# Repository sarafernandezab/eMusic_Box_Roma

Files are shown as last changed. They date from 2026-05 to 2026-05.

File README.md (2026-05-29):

# eMusic Box Roma (eMB Roma)

This repository contains the open-source hardware files, firmware, Max/MSP control patches, musical stimuli, configuration files, and supplementary Python scripts associated with the methodological paper:

> *The e-Music Box Roma: An open research tool for accessible joint music making*  
> Sara F. Abalde, Félix Bigand, Lorenzo Orciari, Claudio Lorini, Peter E. Keller, Alberto Parmiggiani, Marco Crepaldi, Giacomo Novembre    

The eMusic Box Roma (eMB Roma) is an open instrument for accessible music making. It combines a 3D-printed rotary interface, embedded electronics, custom firmware, and Max/MSP software for interactive musical stimulus presentation and experimental control. The system supports both solo and dual use.

---

## Repository structure

```text
.
├── hardware/
│   └── 3D_printing_STL_files
│
├── firmware/
│
├── software/
│   ├── solo_eMB_MaxMSP/
│   └── dual_eMB_MaxMSP/
│
├── musical_stimuli/
│   ├── example_MIDI/
│   └── example_MIDI_derived_text_eMB/
│
├── configs/
│   ├── global/
│   └── experiments/
│
├── supplementary/
│   ├── config_generation/
│   └── analysis/
│
└── README.md
```

---

## Hardware design and construction

The `hardware/3D_printing_STL_files/` folder contains the STL files required to fabricate the eMB Roma enclosure.

The mechanical design is organized according to the three main structural groups described in the paper: base, cover, disk support, rotary disk and locking rings (both inner and outer).

The STL files correspond to the printable components of the eMB Roma illustrated in Figure 2. In the implementation described in the paper, parts were printed in Nylon PA 6-6, although other materials may be used depending on experimental or fabrication constraints.

Additional non-printed mechanical components include the rotating handle, ball bearing, ferrite ring, and self-tapping screws. Assembly details, screw sizes, and component placement are documented in the main paper.

---

## Electronic architecture

The eMB Roma integrates:

- a magnetic rotary encoder for measuring disk rotation,
- a linear slider,
- a push button,
- and a microcontroller for data acquisition and USB communication.

The firmware and software assume that all input signals are streamed from the microcontroller to the core computer through a serial connection over USB.

Hardware-specific wiring diagrams, component lists, and assembly notes are documented in the paper.

---

## Firmware and data communication

The firmware is located in:

```text
firmware/emb_firmware.ino
```

The firmware needs to be uploaded to the microcontroller during initial device setup. During routine use, it reads:

- rotary angle from the magnetic rotary encoder,
- slider position from the linear potentiometer,
- push button state from the digital input.

These values are streamed to the core computer through a serial COM port using ASCII-encoded messages.

The firmware includes device-specific calibration parameters. In particular, the angular zero position can be adjusted using the `value_offset_zero` parameter. This corrects for small differences in encoder and magnet alignment after assembly.

The direction of rotation can also be configured in the firmware. By default, the eMB Roma is set to clockwise rotation. This can be inverted by changing the `rotation_direction` parameter from `CW` to `CCW`. After changing the rotation direction, the zero-reference parameter may need to be verified or adjusted.

Once the firmware has been uploaded and calibration is complete, the Arduino environment should be closed so that the serial port is available to the Max/MSP control patch.

---

## Software architecture and experimental control

Two ready-to-use Max/MSP projects are provided, located in:

| Folder | Description |
|---|---|
| `software/solo_eMB_MaxMSP/` | Max/MSP patch for solo eMB use. |
| `software/dual_eMB_MaxMSP/` | Max/MSP patch for dual eMB use. |

The Max/MSP patch provides a graphical interface for:

- loading configuration files,
- selecting musical stimuli,
- assigning instruments to eMB devices,
- receiving serial data from the eMB,
- mapping rotational position to musical events,
- playing MIDI output streams,
- logging behavioral and musical data,
- and sending optional synchronization triggers to external systems.

---

## Configuration files

Configuration files are located in:

```text
configs/
```

The software uses two main types of configuration files:

| Folder | Description |
|---|---|
| `configs/global/` | Global configuration files containing setup-wide parameters such as COM ports, sampling rate, stimulus paths, output paths, instrument assignments, metronome settings, and optional trigger settings. |
| `configs/experiments/` | Trial-specific experiment configuration files, with one row per trial. These files define parameters such as trial number, condition, song, number of bars, instrument assignment, metronome tempo, and number of metronome beats. |

Configuration files are plain-text files and can be generated automatically using the supplementary Python scripts.

---

## Musical stimuli

Musical stimuli are located in:

```text
musical_stimuli/
```

The eMB Roma uses MIDI-derived text files that can be read by the Max/MSP patch and synchronized with the rotational position of the device. The MIDI derived text are created from the original MIDI using the Python code provided in pipeline_convert_MIDI_to_eMBtxt.py.

| Folder | Description |
|---|---|
| `musical_stimuli/example_MIDI/` | Original MIDI files separated by instrument. |
| `musical_stimuli/example_MIDI_derived_text_eMB/` | Text-based MIDI-derived stimulus files used by the Max/MSP patch. |

By default, one full rotation of the eMB corresponds to one musical bar divided into 16 equally spaced steps, matching the sixteenth-note structure of a 4/4 bar. Each row of a MIDI-derived text file represents a discrete temporal frame. Notes are encoded using MIDI-style values such as pitch, velocity, and duration.

Polyphonic stimuli are supported by including multiple note triplets in the same temporal frame. Frames without musical events are represented as silence.

The conversion scripts support batch conversion of MIDI files and can extract metadata such as tempo and bar count. If a MIDI file contains multiple instruments, the instrumental parts should be separated before conversion, with filenames indicating the corresponding instrument.

---

## Supplementary Python scripts

Supplementary scripts are located in:

```text
supplementary/
```

These scripts support reproducible preparation of files used by the eMB Roma system.

| Folder | Description |
|---|---|
| `supplementary/config_generation/` | Python scripts for generating global and experiment configuration files. |
| `supplementary/utilities/` | Additional utility scripts for preparing or checking repository resources. |
| `supplementary/analysis/` | Optional scripts for inspecting or analyzing output files. |

Example:

```bash
python supplementary/config_generation/create_configs.py
```

---

## Trial execution and data output

During a trial, the Max/MSP patch receives the continuous angular position of each eMB and discretizes it into temporal bins. The discretized within-bar position is combined with the completed rotation count to determine the absolute position in the musical sequence. This absolute position is then used to trigger the corresponding MIDI-derived musical event.

For each completed trial, the Max/MSP patch can save:

1. a raw text data file containing timestamped eMB data,
2. a MIDI file containing the musical output streams,
3. and, when enabled, a summary log file.

The raw text data file contains the main behavioral data used for analysis, including angular position, discretized musical position, rotation cycle count, and instrument information for each connected eMB.

---

## Example use cases

The eMB Roma supports different experimental and musical configurations along two main dimensions:

1. **Musical complexity**  
   The system can be configured for monophonic or polyphonic playback, single or multiple instruments, identical or complementary musical streams, and optional real-time parameter modulation through the linear slider.

2. **Social configuration**  
   The system supports solo use with one eMB and dual use with two eMBs. The repository provides separate Max/MSP patches for these two validated configurations.

Example dual-use configurations include:

- **Unison duet**: both eMBs play the same instrument and musical sequence.
- **Counterpoint duet**: the eMBs play different but complementary musical lines.
- **Band-like duet**: one eMB controls melodic streams while the other controls rhythmic or harmonic streams.

Multi-user setups beyond two devices may be possible with additional software and synchronization development, but they are not included as ready-to-use configurations in this repository.

---

## Quick start

Clone the repository:

```bash
git clone https://github.com/sarafernandezab/eMusic_Box_Roma.git
cd eMusic_Box_Roma
```

Upload the firmware to the microcontroller using the Arduino environment.

Then open the appropriate Max/MSP project:

```text
software/solo_eMB_MaxMSP/
```

or:

```text
software/dual_eMB_MaxMSP/
```

Load the global and experiment configuration files from `configs/`, then select the desired musical stimuli from `musical_stimuli/example_MIDI_derived_text_eMB/` or create your own musical stimuli with the same format.

---

## Dependencies

The repository may require:

- Arduino IDE or compatible Arduino development environment,
- AS5047P Arduino library,
- Max 8 or later,
- Python 3
  
---

## Citation

If you use this repository, please cite:

```bibtex
@article{emb_roma,
  title={The e-Music Box Roma: An open reasearch tool for accessible joint music making},
  author={Abalde, Sara F. and Bigand, Félix and Orciari, Lorenzo and others},
  journal={...},
  year={2026}
}
```

## Contact

For questions, bug reports, or suggestions regarding the eMB Roma system, please contact:

**Sara Fernández Abalde**  
sara.abalde@iit.it

Please include "eMB Roma" in the subject line when reporting issues.

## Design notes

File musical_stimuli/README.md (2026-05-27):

# Musical stimuli

This folder contains the musical materials used by the eMusic Box Roma (eMB Roma), including example MIDI files, MIDI-derived text files formatted for playback by the eMB, and the Python conversion pipeline used to generate them.

The musical stimuli are designed to be synchronized with the rotational data from the eMBs. During playback, the Max/MSP patch reads the MIDI-derived text files frame by frame and maps each frame to the current rotational position of the eMB handle.

---

## Folder structure

```text
musical_stimuli/
├── README.md
├── pipeline_convert_MIDI_to_eMBtxt.py
├── examples_MIDI/
└── example_MIDI_derived_text_eMB/
```

| File or folder | Description |
|---|---|
| `pipeline_convert_MIDI_to_eMBtxt.py` | Python pipeline for converting standard MIDI files into eMB-compatible text files. |
| `examples_MIDI/` | Example MIDI files, separated by instrument, including versions of *Thriller*, *Freed from Desire*, *Get Down on It*, and *We Found Love*. |
| `example_MIDI_derived_text_eMB/` | MIDI-derived text files generated from the example MIDI files and ready to be loaded by the eMB Max/MSP patch. |

---

## Musical stimulus format

All musical materials must be formatted so they can be interpreted and synchronized with the rotational data from the eMB. The eMB system uses simplified text-based representations converted from standard MIDI files.

By default, one full rotation of the eMB corresponds to one musical bar divided into 16 equally spaced steps. This matches the sixteenth-note structure of a 4/4 bar. Each step represents a fixed temporal frame in which one or more musical events may occur.

Each note is represented using MIDI-style values:

```text
pitch velocity duration
```

where:

- `pitch` is the MIDI pitch value,
- `velocity` determines the loudness or intensity of the note,
- `duration` specifies the temporal length of the note.

Polyphonic events are represented by including multiple pitch-velocity-duration triplets in the same row. Frames without musical events are represented as silence, with MIDI values set to zero.

---

## Example stimuli

The folder `examples_MIDI/` contains example MIDI files for different instrumental parts. The examples include versions of:

- *Thriller*
- *Freed from Desire*
- *Get Down on It*
- *We Found Love*

The MIDI files are organized as separate instrument streams, such as drums, bass, keyboards, and violin or melody. Each instrumental part should be saved separately before conversion.

The corresponding eMB-ready text files are provided in:

```text
example_MIDI_derived_text_eMB/
```

These files can be loaded directly by the Max/MSP patch according to the paths specified in the global configuration file.

---

## Converting MIDI files to eMB text files

The conversion from MIDI to eMB-compatible text files is performed with:

```text
pipeline_convert_MIDI_to_eMBtxt.py
```

This script converts standard MIDI files into simplified text files that can be read by the Max/MSP patch during eMB playback.

The conversion pipeline supports:

- conversion of MIDI files separated by instrument,
- polyphonic MIDI sequences,
- batch conversion of multiple MIDI files,
- extraction of stimulus metadata such as tempo and number of frames,
- generation of text files compatible with the eMB rotational mapping.

If a MIDI file contains multiple instruments, the instrumental parts should be separated into different files before conversion. Filenames should indicate the corresponding song and instrument, for example:

```text
Freed_bass.mid
Freed_drums.mid
Freed_keyboard.mid
Freed_violin.mid
```

The generated text files should follow the same naming logic:

```text
Freed_bass.txt
Freed_drums.txt
Freed_keyboard.txt
Freed_violin.txt
```

---

## Using the stimuli in Max/MSP

At the start of an eMB session, the Max/MSP patch loads the MIDI-derived text files according to the paths defined in the global configuration file.

During playback:

1. the eMB streams rotational data to the computer,
2. the Max/MSP patch discretizes the angular position into temporal frames,
3. the corresponding row of the MIDI-derived text file is read,
4. the musical event for that frame is played through the assigned MIDI instrument stream.

This structure allows individual instrument streams to be flexibly assigned, combined, or synchronized across one or two eMB devices.

---

## Notes on editing stimuli

The MIDI-derived text format can be edited manually in any text editor or regenerated by modifying the Python conversion pipeline.

For example, to transpose a stimulus down by one octave, subtract `12` from the pitch value of each note.

When editing files manually, preserve the row structure so that the number and order of frames remain compatible with the Max/MSP patch and the expected rotational mapping.

---

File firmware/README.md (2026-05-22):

# eMB Roma Firmware

This folder contains the Arduino firmware (eMB_firmware.ino) used to operate the eMusic Box Roma after assembly.

The firmware acquires:

- rotary angle data from the AS5047P magnetic rotary encoder,
- linear slider position,
- push button state,

and streams these values in real time to the core computer through a serial USB connection.

---

## Hardware requirements

The firmware was developed for:

- Adafruit Feather M0 microcontroller
- AS5047P magnetic rotary encoder
- Linear slider potentiometer
- Push button

The AS5047P encoder communicates with the microcontroller through SPI.

---

## Dependencies

Install the following Arduino library before compiling:

- AS5047P Arduino library  
  https://github.com/jonas-merkle/AS5047P

---

## Firmware configuration

Two parameters may need to be adjusted for each individual eMB after assembly:

```cpp
float value_offset_zero = 118.0;
RotationDirection rotation_direction = CW;
```

### Zero-position calibration

`value_offset_zero` defines the angular offset corresponding to the desired 0° position of the device.

After assembling the eMB:

1. Upload the firmware.
2. Open the Arduino serial monitor.
3. Rotate the device to the desired zero position.
4. Adjust `value_offset_zero` until the reported angle corresponds to 0°.

This calibration only needs to be performed once unless the encoder or magnet position changes.

---

## Rotation direction

The direction of rotation can be configured as:

```cpp
CW
```

or:

```cpp
CCW
```

Clockwise (`CW`) rotation is the default behavior.

---

## Serial output

The firmware streams ASCII-encoded values through the serial port at 9600 baud in the following format:

```text
slider_value corrected_angle
```

Example:

```text
523 142.31
```

---

## Uploading the firmware

1. Open the `.ino` file in the Arduino IDE.
2. Select the correct board and COM port.
3. Compile and upload the firmware.
4. Close the Arduino serial monitor before starting the Max/MSP patch so the serial port becomes available.

---

## Related software

The streamed serial data are used by the Max/MSP control patches located in:

```text
software/max_msp/
```

These patches handle:

- real-time acquisition,
- musical event mapping,
- MIDI playback,
- synchronization,
- and experimental control.

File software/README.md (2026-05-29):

# eMB Roma — Max/MSP Projects

Max/MSP projects for real-time musical interaction and experimental control using the eMB Roma devices.

This repository contains two versions of the Max/MSP implementation:

```text
solo_eMB_maxMSP/
dual_eMB_maxMSP/
```

Both projects share the same software architecture and functionality as described in the article. The main difference is the number of supported eMB devices:

* `solo_eMB_maxMSP` → setup for one eMB
* `dual_eMB_maxMSP` → setup for two simultaneous eMBs

---

## Project Structure

```text
solo_eMB_maxMSP/
│
├── eMB_solo_.maxpat
├── data/
├── other/
└── patchers/

dual_eMB_maxMSP/
│
├── eMB_dual_.maxpat
├── data/
├── other/
└── patchers/
```

---

## Features

* Real-time eMB rotational data acquisition
* Musical stimulus playback
* MIDI generation from movement
* Experimental trial control
* Instrument mapping
* Behavioral data logging
* Optional synchronization triggers for external devices

Both versions support:

* configurable experimental trials
* polyphonic musical stimuli
* MIDI-derived text sequences
* external MIDI routing

---

## Running the Projects

1. Open the desired project:

   * `solo_eMB_maxMSP/main.maxpat`
   * `dual_eMB_maxMSP/main.maxpat`

2. Load:

   * global configuration file
   * experiment configuration file

3. Connect the eMB device(s)

4. Start DSP/audio, and activate the patch data flow by pressing X.

5. After selecting the desired experiment, trial and song, press `Start Trial` in O

---

## Configuration Files

Each project uses two configuration files:

### Global Configuration

Defines:

* COM ports
* sampling rate
* paths
* instrument assignments
* trigger settings

### Experiment Configuration

Defines trial-specific parameters:

* song
* condition
* instrument mapping
* tempo
* metronome settings

---

## Musical Stimuli

Stimuli are stored as MIDI-derived text files:

```text
<song>_<instrument>.txt
```

Supported:

* monophonic and polyphonic MIDI-derived sequences
* multiple instruments
* configurable mappings

---

## Outputs

Each trial generates:

* raw behavioral data logs
* MIDI output files
* optional summary logs

---

## Screenshots

### GUI Overview

* Graphical user interface view with MaxMSP locked, for easier visualization and interaction with the eMB Roma. Press X to start the eMB connection and O to start a trial after loading the experimental configuration file and corresponding  trial (and song).

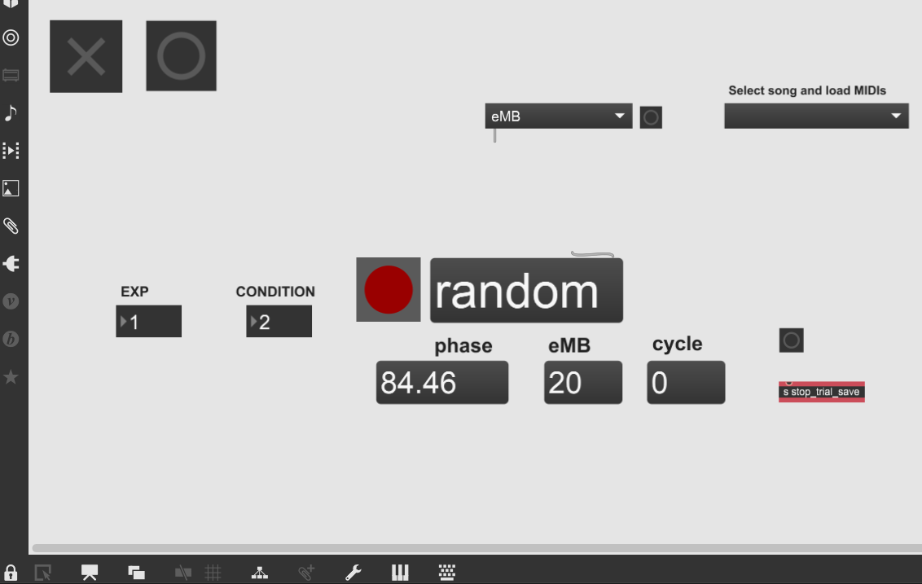
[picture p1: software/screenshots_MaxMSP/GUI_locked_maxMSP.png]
GUI Overview locked


* View of hidden MaxMSP objects with unlocked view.

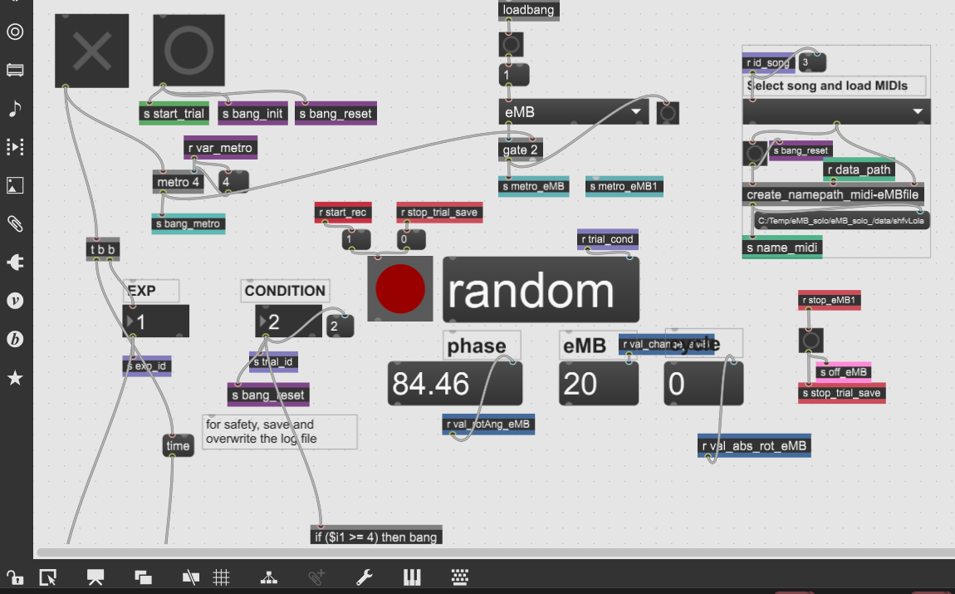
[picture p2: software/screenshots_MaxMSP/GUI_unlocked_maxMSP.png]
GUI Overview unlocked


---

### Configuration and initialization

Block for loading paths, instruments and other initialization variables. 

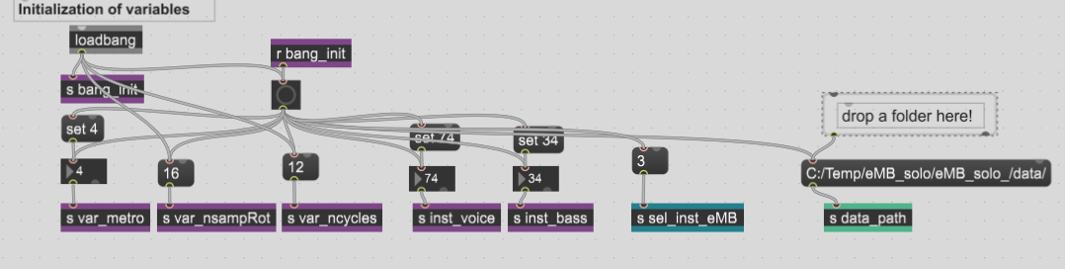
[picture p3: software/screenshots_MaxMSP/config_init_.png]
Configuration and initialization


---

### eMB angle and linear slider acquisition

Block that receives the eMB data and processes it following the logic described in the manuscript section 'Trial execution and data flow'.

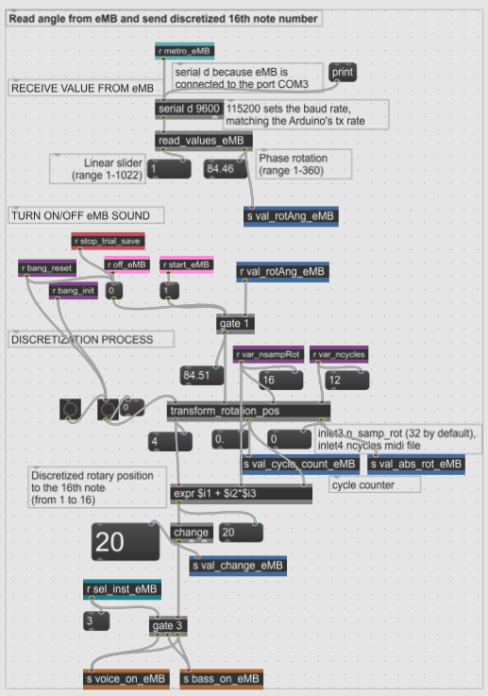
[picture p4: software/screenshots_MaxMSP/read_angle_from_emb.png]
eMB data acquisition


---

### Instrument mapping and playback

Example block for instrument 1 illustrating the data flow for mapping the eMB data into MIDI playback.

Instrument mapping and playback

---

### Data output and logging

Block that saves the eMB data into the raw data text file.

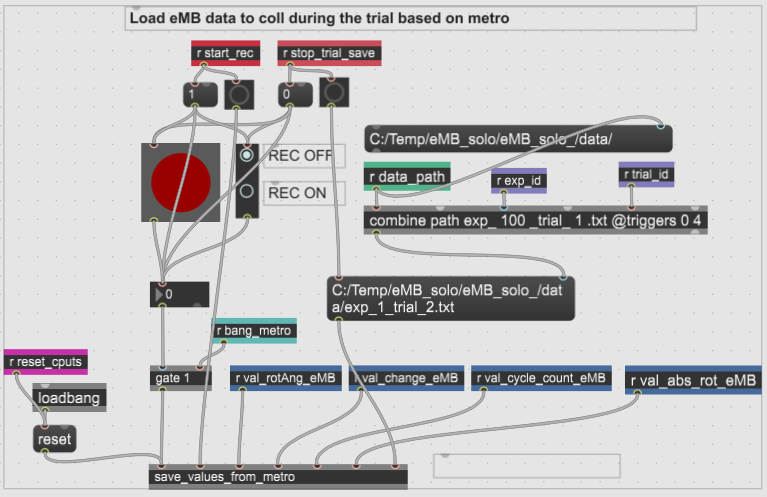
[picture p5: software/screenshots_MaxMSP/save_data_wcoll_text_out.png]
Software Pipeline


Block that saves the MIDI file with polyphony, with each instrument on a different channel.

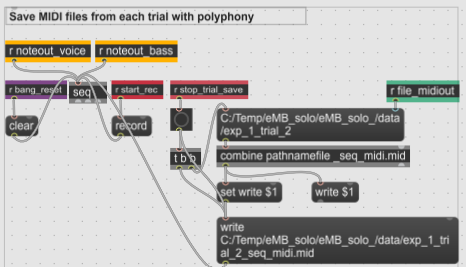
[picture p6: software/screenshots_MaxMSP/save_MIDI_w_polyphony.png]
Software Pipeline


---

### Synchronization with external devices

The Max/MSP patch can optionally send synchronization triggers through COM ports. These triggers can mark events such as trial onset, trial offset, or predefined rhythmic positions. This feature is intended for synchronization with external recording systems such as EEG, motion capture, or other multimodal acquisition devices.

Screenshots below show example blocks for detecting and sending triggers to an EEG serial COM port. 

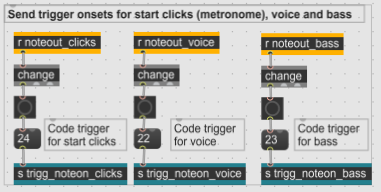
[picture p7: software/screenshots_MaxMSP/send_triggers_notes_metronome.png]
Detect triggers


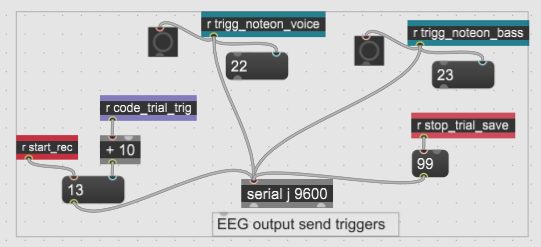
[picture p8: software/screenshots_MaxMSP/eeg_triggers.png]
Triggers to serial port


---

## Notes

* Default discretization: 16 steps per rotation
* Default sampling rate: 200 Hz
* The dual version processes both eMBs independently in parallel
* Trigger outputs for EEG or external systems are optional

---

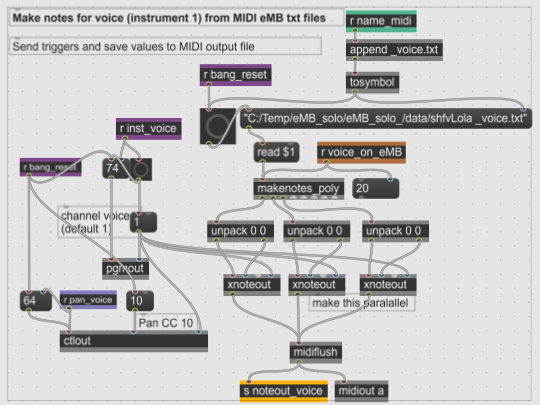
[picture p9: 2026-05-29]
software/screenshots_MaxMSP/play_instrument.png

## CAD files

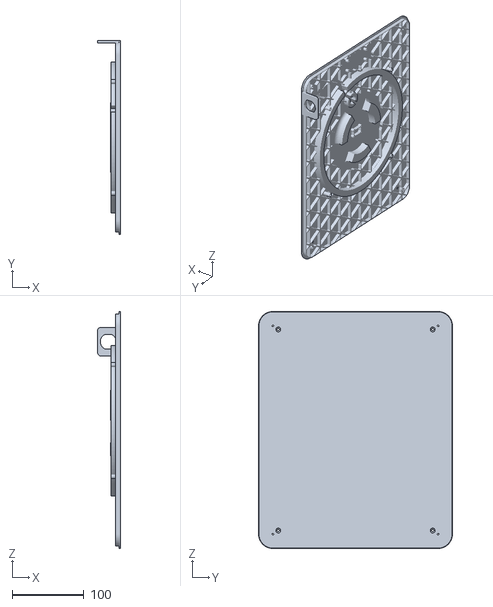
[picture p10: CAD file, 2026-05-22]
hardware/3D_printing_STL_files/base_eMB_mws_bmp016.stl
32.0 x 270.0 x 330.0

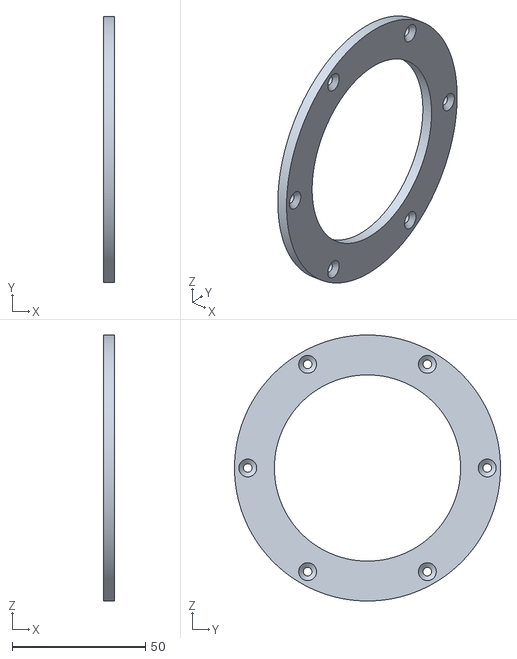
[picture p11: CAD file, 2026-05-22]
hardware/3D_printing_STL_files/locking_ring_outer_eMB_mws_bmp016.stl
4.00 x 100.0 x 100.0

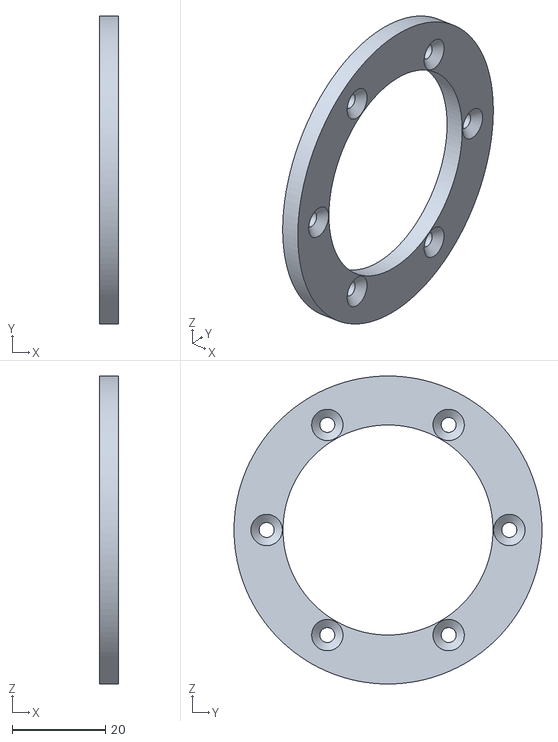
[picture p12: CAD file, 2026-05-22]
hardware/3D_printing_STL_files/locking_ring_inner_eMB_mws_bmp016.stl
4.00 x 66.0 x 66.0

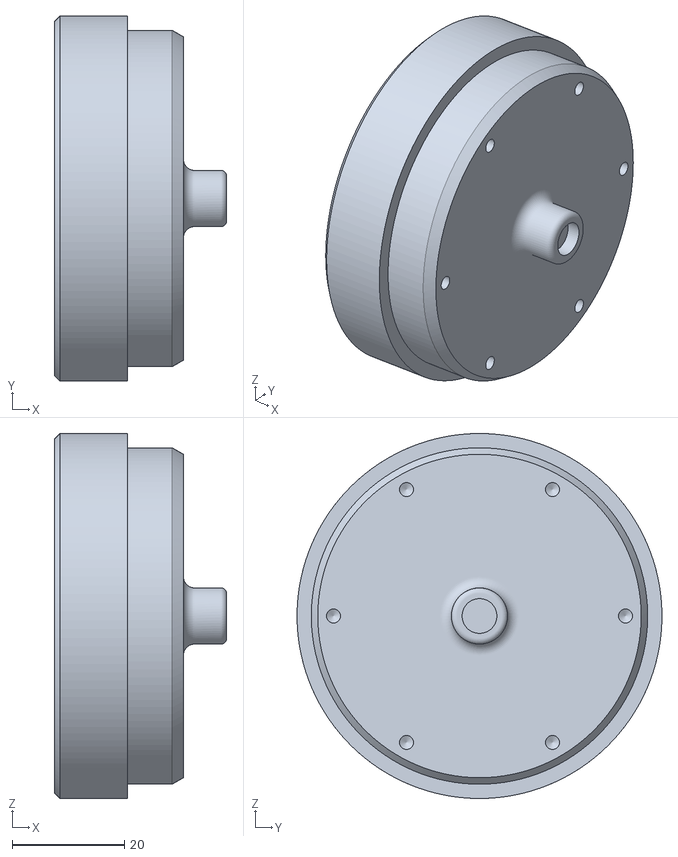
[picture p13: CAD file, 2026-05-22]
hardware/3D_printing_STL_files/disk_support_eMB_mws_bmp016.stl
30.7 x 65.0 x 65.0

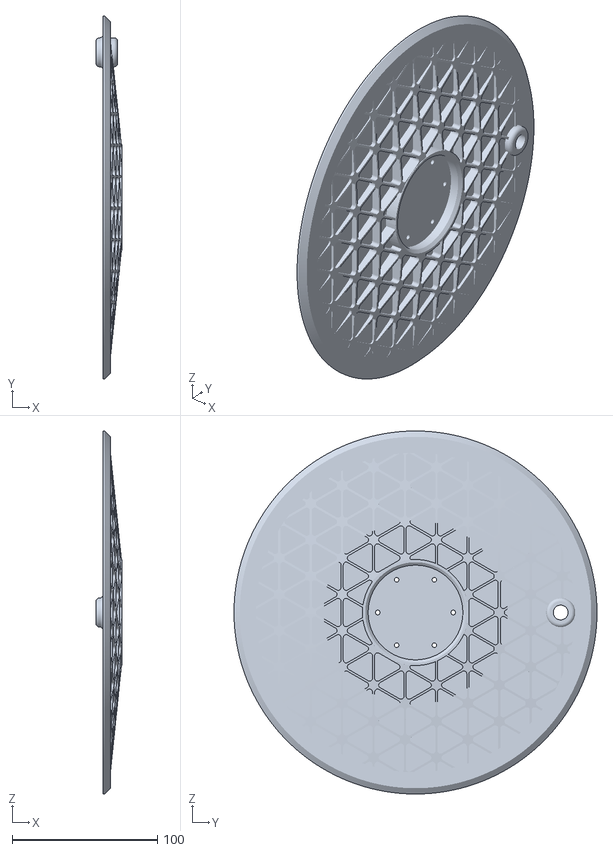
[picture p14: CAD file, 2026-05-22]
hardware/3D_printing_STL_files/rotary_disk_eMB_mws_bmp016.stl
18.0 x 250.0 x 250.0

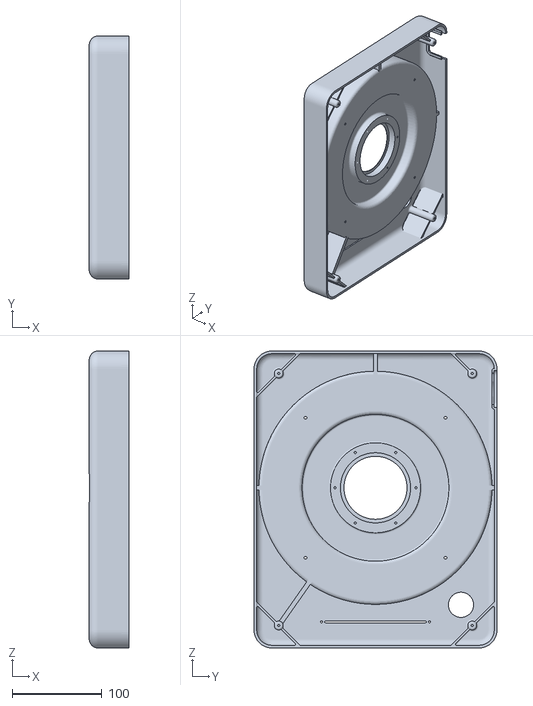
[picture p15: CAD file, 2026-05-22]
hardware/3D_printing_STL_files/cover_eMB_mws_bmp016.stl
44.0 x 270.0 x 330.0

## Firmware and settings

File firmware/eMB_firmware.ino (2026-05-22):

/*
  eMusic Box Roma firmware

  Hardware connections:
  - Linear slider potentiometer:
      GND, 3.3V, A0
  - AS5047P magnetic rotary encoder:
      3.3V, GND, MISO, MOSI, SCK, CS -> pin 9
  - Push button:
      digital input on pin 5
  - On-board LED:
      pin 13

  AS5047P setup:
  - Install the AS5047P Arduino library.
  - Mount R2 on AS5047P board.
  - Remove JP1 default connection.
  - Short JP1.2 and JP1.3 for 3.3 V operation.

  Serial output format:
      slider_value corrected_angle

  Notes:
  - value_offset_zero defines the raw encoder angle corresponding to 0 degrees.
  - rotation_direction can be set to CW or CCW.
*/

#include <AS5047P.h>
#include <math.h>

// -------------------------
// Pin definitions
// -------------------------

#define SLIDER_PIN A0
#define LED_PIN 13
#define BUTTON_PIN 5

#define AS5047P_CHIP_SELECT_PIN 9
#define AS5047P_SPI_BUS_SPEED 100000

// -------------------------
// Rotation configuration
// -------------------------

enum RotationDirection {
  CW,
  CCW
};

// Change this to CCW if you want counterclockwise rotation mapping
RotationDirection rotation_direction = CW;

// Device-specific zero-position offset.
// Change this value after calibration for each eMB.
float value_offset_zero = 118.0;

// -------------------------
// Global variables
// -------------------------

AS5047P encoder(AS5047P_CHIP_SELECT_PIN, AS5047P_SPI_BUS_SPEED);

const float FULL_ROTATION_DEGREES = 360.0;

// -------------------------
// Helper functions
// -------------------------

float wrapAngle360(float angle) {
  float wrapped = fmod(angle, FULL_ROTATION_DEGREES);

  if (wrapped < 0) {
    wrapped += FULL_ROTATION_DEGREES;
  }

  return wrapped;
}

float getCorrectedAngle(float raw_angle) {
  // First align raw encoder angle to calibrated 0–360 degree range
  float corrected_angle = wrapAngle360(raw_angle - value_offset_zero);

  // If counterclockwise mapping is selected, mirror the angle
  if (rotation_direction == CCW) {
    corrected_angle = wrapAngle360(FULL_ROTATION_DEGREES - corrected_angle);
  }

  return corrected_angle;
}

// -------------------------
// Setup
// -------------------------

void setup() {
  pinMode(LED_PIN, OUTPUT);
  pinMode(BUTTON_PIN, INPUT);

  Serial.begin(9600);

  while (!encoder.initSPI()) {
    Serial.println(F("Cannot connect to the AS5047P sensor."));
    delay(1000);
  }
}

// -------------------------
// Main loop
// -------------------------

void loop() {
  int slider_value = analogRead(SLIDER_PIN);

  float raw_angle = encoder.readAngleDegree();
  float corrected_angle = getCorrectedAngle(raw_angle);

  Serial.print(slider_value);
  Serial.print(" ");
  Serial.println(corrected_angle);

  // Optional button feedback using on-board LED.
  // Uncomment if the button should control the LED.
  /*
  if (digitalRead(BUTTON_PIN) == LOW) {
    digitalWrite(LED_PIN, HIGH);
  } else {
    digitalWrite(LED_PIN, LOW);
  }
  */

  // Optional small delay if needed.
  // delay(1);
}

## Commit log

2026-05-22 add STL files
    [base_eMB_mws_bmp016.stl, cover_eMB_mws_bmp016.stl, disk_support_eMB_mws_bmp016.stl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]
2026-05-22 Add README for eMB Roma firmware
    Added detailed documentation for eMB Roma firmware, including hardware requirements, dependencies, configuration, calibration, and usage instructions.
